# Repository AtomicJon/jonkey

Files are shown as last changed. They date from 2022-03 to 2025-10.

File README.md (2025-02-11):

# JONKEY

The JONKEY is a columnar split keyboard created using [ergogen](https://github.com/ergogen/ergogen).

## v2
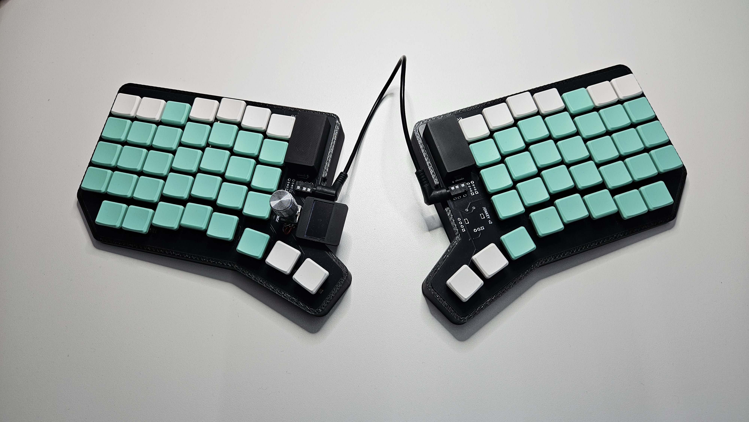
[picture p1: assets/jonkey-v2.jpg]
jonkey v2

#### What's New
- Swap thumb layout
- Added encoder mounts
- Added screen
- TODO: Touchpad mount

### Project Contents
- Ergogen Config: [jonkey-v2.yml](jonkey-v2.yml)
- PCB Design: [pcbs/](pcbs/)
- 3D Printable case: __TODO__
- QMK Config: [qmk_config/](qmk_config/)

## v1
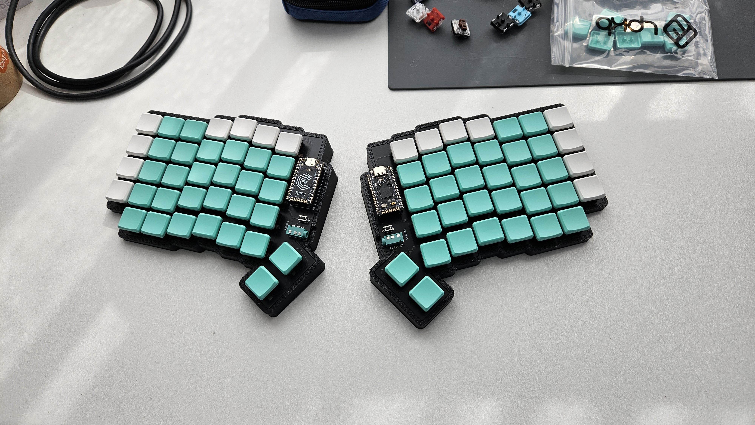
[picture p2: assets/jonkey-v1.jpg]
jonkey v1


### Project Contents
- Ergogen Config: [jonkey.yml](v1/jonkey.yml)
- PCB Design: [v1/pcbs/v1.1/](v1/pcbs/v1.1/)
- 3D Printable case: [case/](v1/case/)
  - The newest version has a 5 degree slope and tighter tolerances
    - [Left](v1/case/Case%20-%20Left%20-%205deg.stl)
    - [Right](v1/case/Case%20-%20Right%20-%205deg.stl)
- QMK Config: [qmk_config/](v1/qmk_config/)

## Notes
- The PCB is a single reversible board, flip it over for the right side
- The Pro Micros need to be attached upside down on the left and right side up on the right for the correct pin alignments
- Currently the QMK firmware has the side hardcoded and needs to be complied individually for each side. To switch between compiling the left/right side firmware, uncomment the appropriate line in the [config.h](v1/qmk_config/atomicjon/jonkey/config.h) (Lines 16/17)
  - There are free pins (D2, D3) that could be used for high/low indication of side

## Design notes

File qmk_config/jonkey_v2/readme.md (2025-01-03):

# atomicjon/jonkey_v2

atomicjon/jonkey_v2

*A short description of the keyboard/project*

* Keyboard Maintainer: [Jon](https://github.com/AtomicJon)
* Hardware Supported: Custom PCB - see the [jonkey](https://github.com/AtomicJon/jonkey) for PCB files
* Hardware Availability: DIY - see above

Before making, ensure the correct target board is configured in [`keyboard.json`](./keyboard.json)
E.g. For pro micro:
```json
"development_board": "promicro",
```

Make example for this keyboard (after setting up your build environment):

    make atomicjon/jonkey_v2:default

Flashing example for this keyboard:

    make atomicjon/jonkey_v2:default:flash

See the [build environment setup](https://docs.qmk.fm/#/getting_started_build_tools) and the [make instructions](https://docs.qmk.fm/#/getting_started_make_guide) for more information. Brand new to QMK? Start with our [Complete Newbs Guide](https://docs.qmk.fm/#/newbs).

## Bootloader

Enter the bootloader in 3 ways:

* **Bootmagic reset**: Hold down the key at (0,0) in the matrix (usually the top left key or Escape) and plug in the keyboard
* **Physical reset button**: Briefly press the button on the back of the PCB - some may have pads you must short instead
* **Keycode in layout**: Press the key mapped to `QK_BOOT` if it is available

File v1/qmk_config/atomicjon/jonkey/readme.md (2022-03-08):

# jonkey

jonkey

*A short description of the keyboard/project*

* Keyboard Maintainer: [Jon](https://github.com/AtomicJon)
* Hardware Supported: *The PCBs, controllers supported*
* Hardware Availability: *Links to where you can find this hardware*

Make example for this keyboard (after setting up your build environment):

    make jonkey:default

Flashing example for this keyboard:

    make jonkey:default:flash

See the [build environment setup](https://docs.qmk.fm/#/getting_started_build_tools) and the [make instructions](https://docs.qmk.fm/#/getting_started_make_guide) for more information. Brand new to QMK? Start with our [Complete Newbs Guide](https://docs.qmk.fm/#/newbs).

## Bootloader

Enter the bootloader in 3 ways:

* **Bootmagic reset**: Hold down the key at (0,0) in the matrix (usually the top left key or Escape) and plug in the keyboard
* **Physical reset button**: Briefly press the button on the back of the PCB - some may have pads you must short instead
* **Keycode in layout**: Press the key mapped to `RESET` if it is available

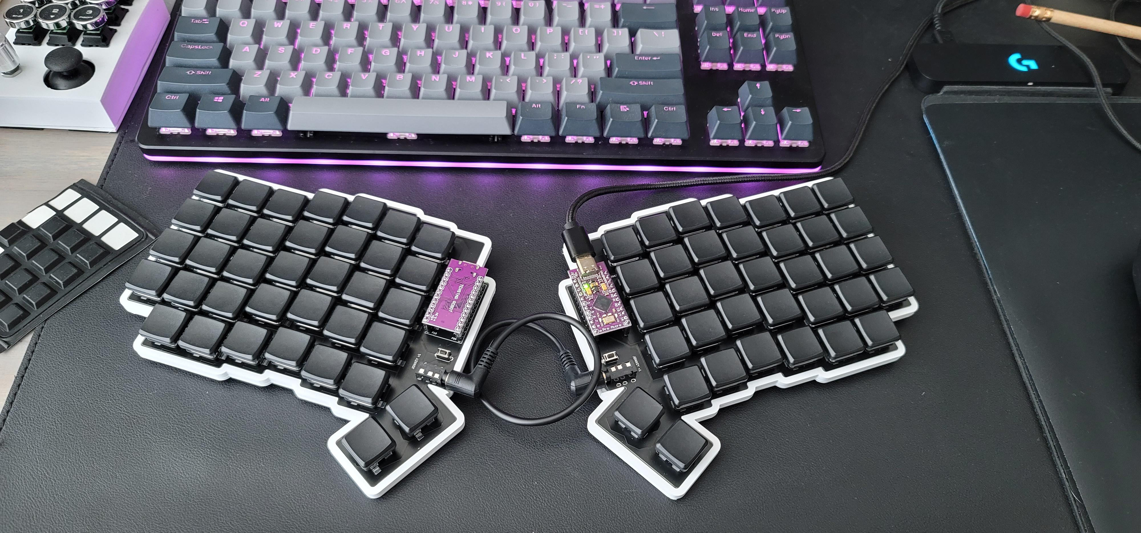
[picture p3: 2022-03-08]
assets/jonkey-v1.orig.jpg

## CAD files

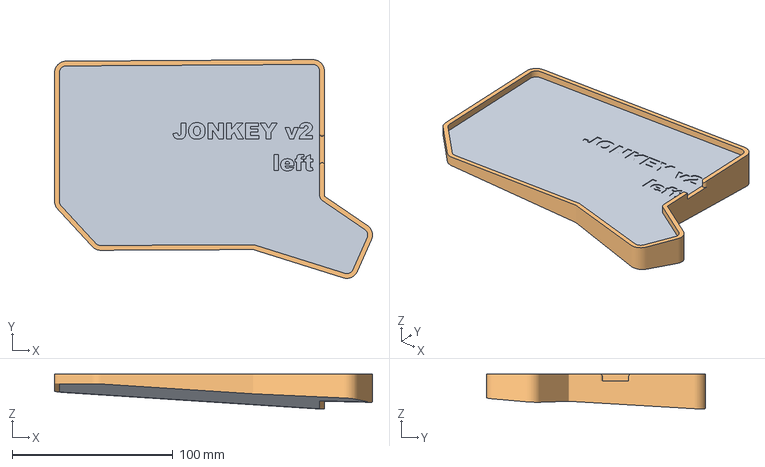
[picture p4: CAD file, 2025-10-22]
case/CaseLeft.3mf
197.9 x 136.1 x 21.7 mm

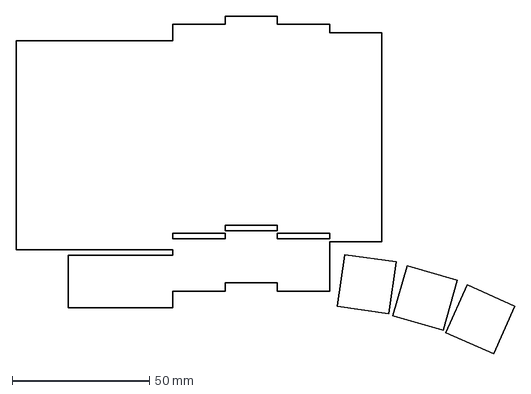
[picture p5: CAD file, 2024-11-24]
ergogen_output/keys.dxf
181.3 x 122.8 mm

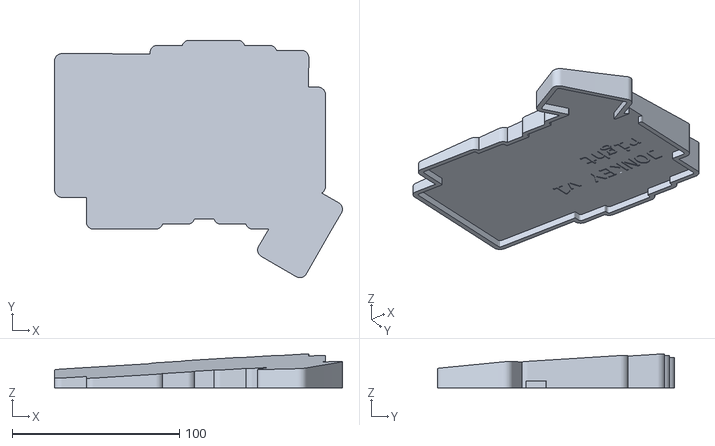
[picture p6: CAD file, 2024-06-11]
v1/case/Case - Right - 5deg.stl
172.1 x 141.8 x 20.3

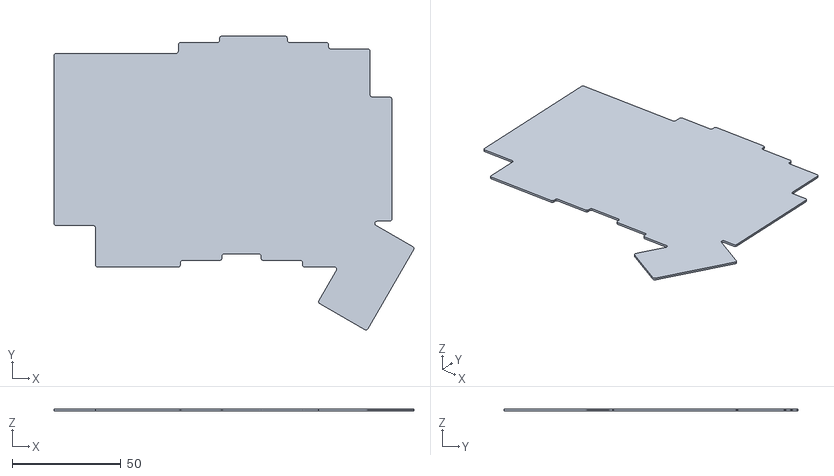
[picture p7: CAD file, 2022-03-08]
v1/ergogen_output/jonkey/cases/baseplate.stl
165.1 x 134.9 x 1.00

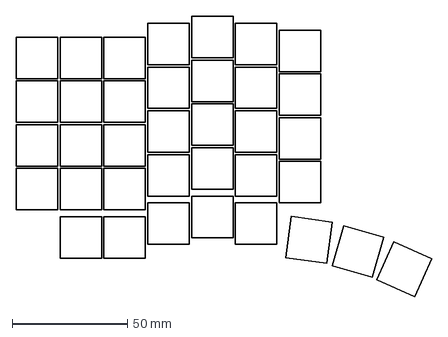
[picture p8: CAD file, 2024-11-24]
ergogen_output/demo.dxf
180.2 x 121.7 mm

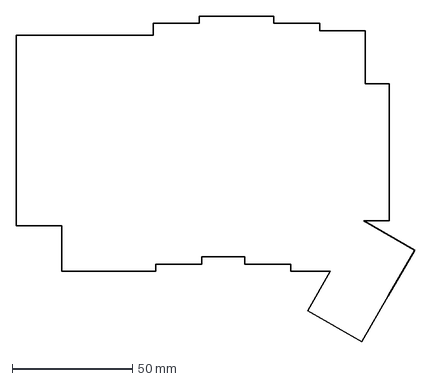
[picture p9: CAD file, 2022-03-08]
v1/ergogen_output/jonkey/outlines/raw.dxf
165.5 x 135.3 mm

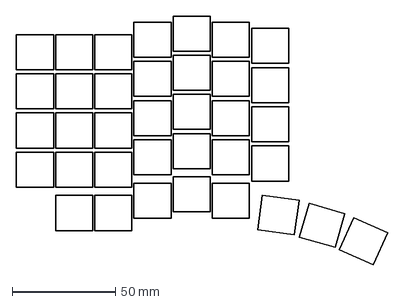
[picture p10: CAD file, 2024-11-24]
ergogen_output/keycap_outlines.dxf
180.0 x 120.7 mm

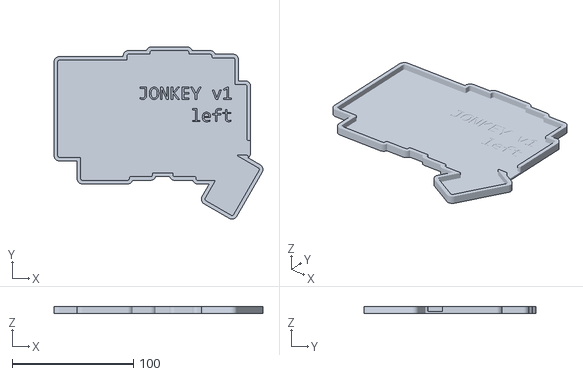
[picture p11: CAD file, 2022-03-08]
v1/case/Case - Left - v1.stl
172.2 x 141.9 x 5.80

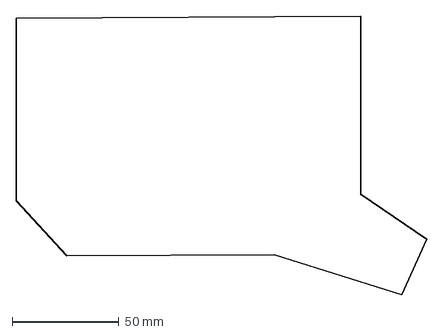
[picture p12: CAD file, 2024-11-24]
ergogen_output/board.dxf
192.4 x 130.6 mm

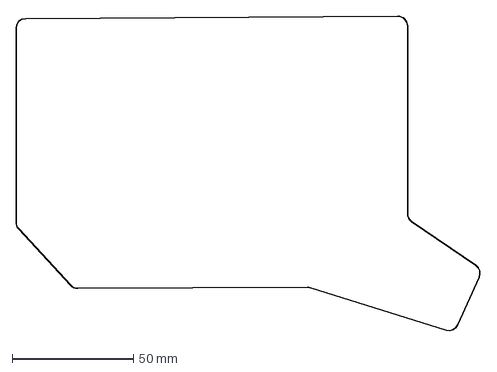
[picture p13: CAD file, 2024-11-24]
ergogen_output/cutout.dxf
191.8 x 130.1 mm

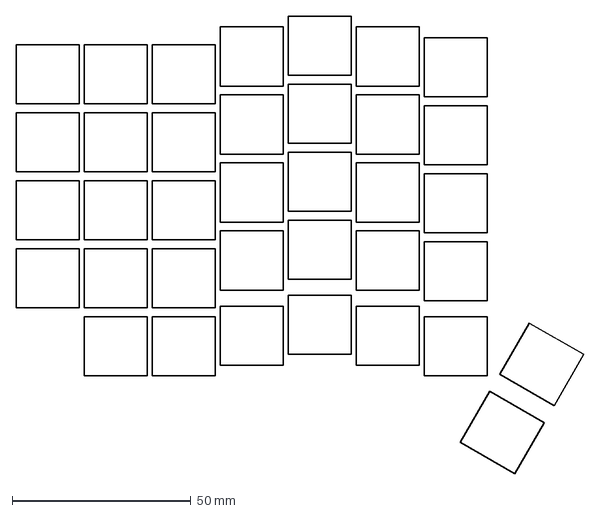
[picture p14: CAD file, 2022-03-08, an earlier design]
v1/ergogen_output/jonkey/outlines/keycap_outlines.dxf
158.5 x 127.8 mm

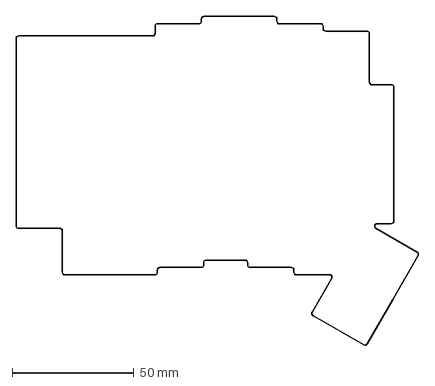
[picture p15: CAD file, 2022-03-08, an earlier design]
v1/ergogen_output/jonkey/outlines/cutout.dxf
165.3 x 135.1 mm

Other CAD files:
case/CaseRight.3mf
v1/case/Case - Left - 5deg.stl
v1/case/Case - Right - v1.stl
case/CaseLeft.stl
case/CaseRight.stl

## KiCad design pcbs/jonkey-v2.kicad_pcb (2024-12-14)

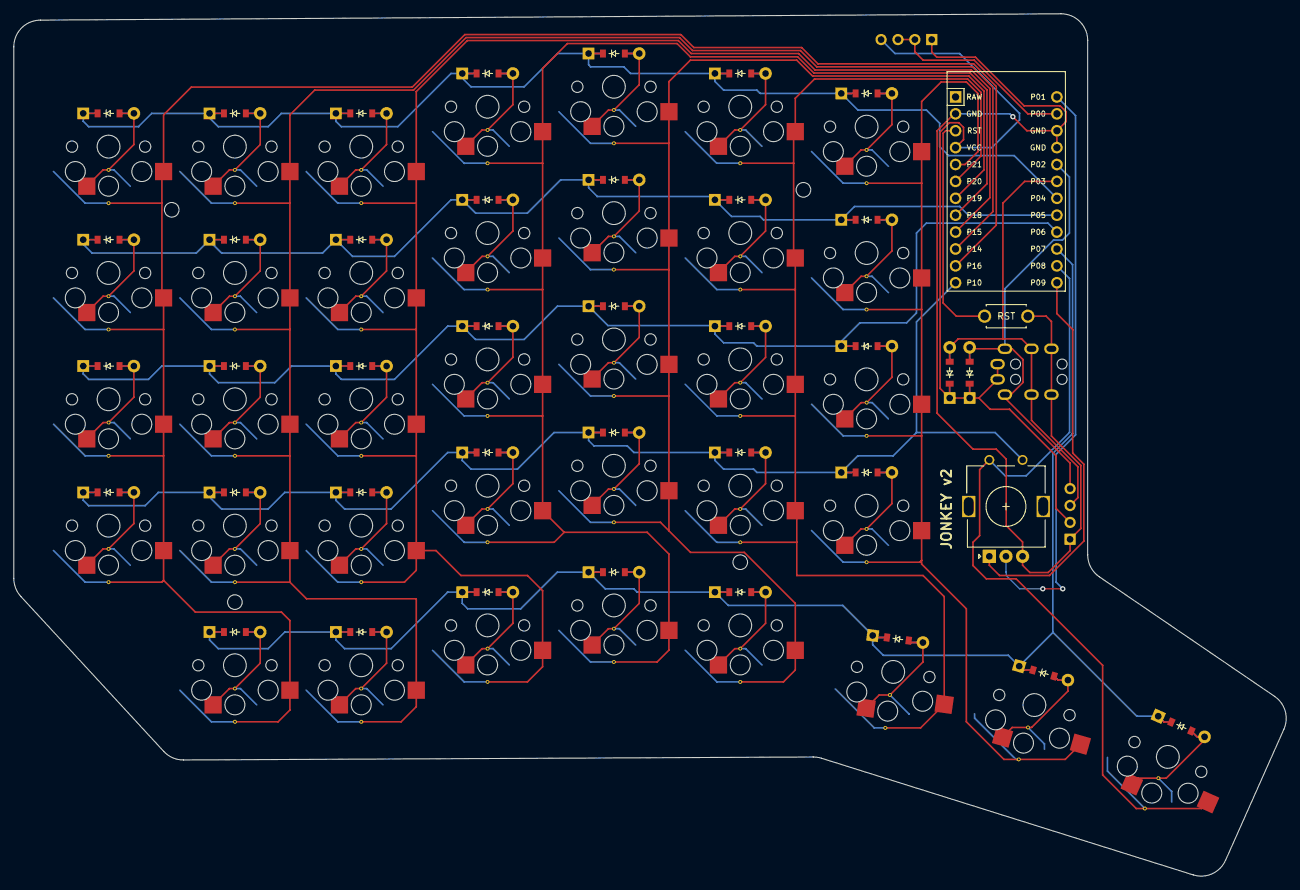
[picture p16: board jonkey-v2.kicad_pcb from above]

Board: 2 copper layers, 191.4 x 129.7 mm, 84 parts (0 on the bottom side), 57 nets.

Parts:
D1, D2, D3, D4, D5, D6, D7, D8, D9, D10, D11, D12, D13, D14, D15, D16, D17, D18, D19, D20, D21, D22, D23, D24, D25, D26, D27, D28, D29, D30, D31, D32, D33, D34, D35, D36: ComboDiode
MCU1: ProMicro
MH1, MH2, MH3, MH4: mounting_hole_npth
OLED1: OLED; OLED_headers
R11, R21: ComboDiode
ROT1: rotary_encoder
RST1: reset_switch_tht_top
S1, S2, S3, S4, S5, S6, S7, S8, S9, S10, S11, S12, S13, S14, S15, S16, S17, S18, S19, S20, S21, S22, S23, S24, S25, S26, S27, S28, S29, S30, S31, S32, S33, S34, S35, S36: PG1350
SERIAL1: SERIAL; OLED_headers
TRRS1: TRRS-PJ-320A-dual

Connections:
GND: MCU1.2, MCU1.15, MCU1.16, OLED1.1, ROT1.B, RST1.1, SERIAL1.1, TRRS1.4
P0: MCU1.14, SERIAL1.2, SERIAL1.3
P1: MCU1.13, ROT1.C
P2: MCU1.17, OLED1.4, R21.2, TRRS1.2
P3: MCU1.18, OLED1.3, R11.2, TRRS1.3
P4: D4.1, D9.1, D14.1, D19.1, D24.1, D29.1, D33.1, MCU1.19
P5: D3.1, D8.1, D13.1, D18.1, D23.1, D28.1, D32.1, MCU1.20
P6: D2.1, D7.1, D12.1, D17.1, D22.1, D27.1, D31.1, MCU1.21
P7: D5.1, D10.1, D15.1, D20.1, D25.1, D34.1, D35.1, D36.1, MCU1.22
P8: MCU1.23, ROT1.1, S36.2
P9: MCU1.24, ROT1.A
P10: D1.1, D6.1, D11.1, D16.1, D21.1, D26.1, D30.1, MCU1.12, ROT1.2
P14: MCU1.10, S6.2, S7.2, S8.2, S9.2, S10.2
P15: MCU1.9, S11.2, S12.2, S13.2, S14.2, S15.2
P16: MCU1.11, S1.2, S2.2, S3.2, S4.2, S5.2
P18: MCU1.8, S16.2, S17.2, S18.2, S19.2, S20.2
P19: MCU1.7, S21.2, S22.2, S23.2, S24.2, S25.2
P20: MCU1.6, S26.2, S27.2, S28.2, S29.2, S34.2
P21: MCU1.5, S30.2, S31.2, S32.2, S33.2, S35.2
RST: MCU1.3, RST1.2
VCC: MCU1.4, OLED1.2, R11.1, R21.1, SERIAL1.4, TRRS1.1
index_bottom: D26.2, S26.1
index_home: D27.2, S27.1
index_modifiers: D25.2, S25.1
index_numbers: D29.2, S29.1
index_top: D28.2, S28.1
inner1_bottom: D30.2, S30.1
inner1_home: D31.2, S31.1
inner1_numbers: D33.2, S33.1
inner1_thumbrow: D34.2, S34.1
inner1_top: D32.2, S32.1
middle_bottom: D21.2, S21.1
middle_home: D22.2, S22.1
middle_modifiers: D20.2, S20.1
middle_numbers: D24.2, S24.1
middle_top: D23.2, S23.1
outer1_bottom: D6.2, S6.1
outer1_home: D7.2, S7.1
outer1_modifiers: D5.2, S5.1
outer1_numbers: D9.2, S9.1
outer1_top: D8.2, S8.1
outer2_bottom: D1.2, S1.1
outer2_home: D2.2, S2.1
outer2_numbers: D4.2, S4.1
outer2_top: D3.2, S3.1
pinky_bottom: D11.2, S11.1
pinky_home: D12.2, S12.1
pinky_modifiers: D10.2, S10.1
pinky_numbers: D14.2, S14.1
pinky_top: D13.2, S13.1
ring_bottom: D16.2, S16.1
ring_home: D17.2, S17.1
ring_modifiers: D15.2, S15.1
ring_numbers: D19.2, S19.1
ring_top: D18.2, S18.1
thumb1_thumbrow: D35.2, S35.1
thumb2_thumbrow: D36.2, S36.1

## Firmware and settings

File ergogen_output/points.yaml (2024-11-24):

matrix_outer2_bottom:
  x: 0
  'y': 21
  r: 0
  meta:
    stagger: 0
    spread: 19
    splay: 0
    origin:
      - 0
      - 0
    orient: 0
    shift:
      - 0
      - 0
    rotate: 0
    adjust: {}
    width: 18
    height: 18
    padding: 19
    autobind: 10
    skip: false
    asym: both
    colrow: outer2_bottom
    name: matrix_outer2_bottom
    column_net: P16
    row_net: P10
    bind:
      - 1
      - 1
      - 1
      - 1
    zone: &ref_1
      columns:
        outer2: &ref_0
          key:
            column_net: P16
          rows:
            modifiers:
              skip: true
          name: outer2
        outer1: &ref_2
          key:
            stagger: 0
            column_net: P14
          rows:
            modifiers:
              column_net: P16
          name: outer1
        pinky: &ref_3
          key:
            stagger: 0
            column_net: P15
          rows:
            modifiers:
              column_net: P14
          name: pinky
        ring: &ref_4
          key:
            stagger: 6
            column_net: P18
          rows:
            modifiers:
              column_net: P15
          name: ring
        middle: &ref_5
          key:
            stagger: 3
            column_net: P19
          rows:
            modifiers:
              column_net: P18
          name: middle
        index: &ref_6
          key:
            stagger: -3
            column_net: P20
          rows:
            modifiers:
              column_net: P19
          name: index
        inner1: &ref_7
          key:
            stagger: -3
            column_net: P21
          rows:
            modifiers:
              skip: true
          name: inner1
      rows:
        modifiers:
          row_net: P7
          padding: u + 2
          bind:
            - 1
            - 1
            - 1
            - 1
        bottom:
          row_net: P10
          bind:
            - 1
            - 1
            - 1
            - 1
        home:
          row_net: P6
          bind:
            - 1
            - 1
            - 1
            - 1
        top:
          row_net: P5
          bind:
            - 1
            - 1
            - 1
            - 1
        numbers:
          row_net: P4
          bind:
            - 4
            - 1
            - 1
            - 1
      name: matrix
    col: *ref_0
    row: bottom
matrix_outer2_home:
  x: 0
  'y': 40
  r: 0
  meta:
    stagger: 0
    spread: 19
    splay: 0
    origin:
      - 0
      - 0
    orient: 0
    shift:
      - 0
      - 0
    rotate: 0
    adjust: {}
    width: 18
    height: 18
    padding: 19
    autobind: 10
    skip: false
    asym: both
    colrow: outer2_home
    name: matrix_outer2_home
    column_net: P16
    row_net: P6
    bind:
      - 1
      - 1
      - 1
      - 1
    zone: *ref_1
    col: *ref_0
    row: home
matrix_outer2_top:
  x: 0
  'y': 59
  r: 0
  meta:
    stagger: 0
    spread: 19
    splay: 0
    origin:
      - 0
      - 0
    orient: 0
    shift:
      - 0
      - 0
    rotate: 0
    adjust: {}
    width: 18
    height: 18
    padding: 19
    autobind: 10
    skip: false
    asym: both
    colrow: outer2_top
    name: matrix_outer2_top
    column_net: P16
    row_net: P5
    bind:
      - 1
      - 1
      - 1
      - 1
    zone: *ref_1
    col: *ref_0
    row: top
matrix_outer2_numbers:
  x: 0
  'y': 78
  r: 0
  meta:
    stagger: 0
    spread: 19
    splay: 0
    origin:
      - 0
      - 0
    orient: 0
    shift:
      - 0
      - 0
    rotate: 0
    adjust: {}
    width: 18
    height: 18
    padding: 19
    autobind: 10
    skip: false
    asym: both
    colrow: outer2_numbers
    name: matrix_outer2_numbers
    column_net: P16
    row_net: P4
    bind:
      - 4
      - 1
      - 1
      - 1
    zone: *ref_1
    col: *ref_0
    row: numbers
matrix_outer1_modifiers:
  x: 19
  'y': 0
  r: 0
  meta:
    stagger: 0
    spread: 19
    splay: 0
    origin:
      - 0
      - 0
    orient: 0
    shift:
      - 0
      - 0
    rotate: 0
    adjust: {}
    width: 18
    height: 18
    padding: 21
    autobind: 10
    skip: false
    asym: both
    colrow: outer1_modifiers
    name: matrix_outer1_modifiers
    column_net: P16
    row_net: P7
    bind:
      - 1
      - 1
      - 1
      - 1
    zone: *ref_1
    col: *ref_2
    row: modifiers
matrix_outer1_bottom:
  x: 19
  'y': 21
  r: 0
  meta:
    stagger: 0
    spread: 19
    splay: 0
    origin:
      - 0
      - 0
    orient: 0
    shift:
      - 0
      - 0
    rotate: 0
    adjust: {}
    width: 18
    height: 18
    padding: 19
    autobind: 10
    skip: false
    asym: both
    colrow: outer1_bottom
    name: matrix_outer1_bottom
    column_net: P14
    row_net: P10
    bind:
      - 1
      - 1
      - 1
      - 1
    zone: *ref_1
    col: *ref_2
    row: bottom
matrix_outer1_home:
  x: 19
  'y': 40
  r: 0
  meta:
    stagger: 0
    spread: 19
    splay: 0
    origin:
      - 0
      - 0
    orient: 0
    shift:
      - 0
      - 0
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

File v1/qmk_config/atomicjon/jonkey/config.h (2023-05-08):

// Copyright 2022 Jon (@AtomicJon)
// SPDX-License-Identifier: GPL-2.0-or-later

#pragma once

// Should no longer be included
// #include "config_common.h"

/* USB Device descriptor parameter */
/*
⚠ atomicjon/jonkey: PRODUCT_ID in config.h is deprecated in favor of `usb.pid` in info.json and will be removed at a later date
⚠ atomicjon/jonkey: VENDOR_ID in config.h is deprecated in favor of `usb.vid` in info.json and will be removed at a later date
⚠ atomicjon/jonkey: PRODUCT in config.h is deprecated in favor of `keyboard_name` in info.json and will be removed at a later date
⚠ atomicjon/jonkey: MANUFACTURER in config.h is deprecated in favor of `manufacturer` in info.json and will be removed at a later date
⚠ atomicjon/jonkey: DEVICE_VER in config.h is deprecated in favor of `usb.device_version` in info.json and will be removed at a later date
*/
// #define VENDOR_ID    0xFEED
// #define PRODUCT_ID   0x0000
// #define DEVICE_VER   0x0001
// #define MANUFACTURER AtomicJon
// #define PRODUCT      jonkey

// Hardcoding handedness for now
#define MASTER_RIGHT
// #define MASTER_LEFT


/* key matrix size */
// Rows * 2 for left and right
#define MATRIX_ROWS 12
#define MATRIX_COLS 8

/*
 * Keyboard Matrix Assignments
 *
 * Change this to how you wired your keyboard
 * COLS: AVR pins used for columns, left to right
 * ROWS: AVR pins used for rows, top to bottom
 * DIODE_DIRECTION: COL2ROW = COL = Anode (+), ROW = Cathode (-, marked on diode)
 *                  ROW2COL = ROW = Anode (+), COL = Cathode (-, marked on diode)
 *
 */
// By Pin:              {  4,  5,  6, 10,  7,  8 }
#define MATRIX_ROW_PINS { D4, C6, D7, B6, E6, B4 }
// By Pin:              { 16, 14, 15, 18, 19, 20, 21,  9 }
#define MATRIX_COL_PINS { B2, B3, B1, F7, F6, F5, F4, B5 }
// By Pin:              { 0,   1 }
#define UNUSED_PINS     { D2, D3 }

/* COL2ROW, ROW2COL */
#define DIODE_DIRECTION COL2ROW

/*
 * Split Keyboard specific options, make sure you have 'SPLIT_KEYBOARD = yes' in your rules.mk, and define SOFT_SERIAL_PIN.
 */
// Pin 2 and 3 are cross connected via TRS, using 2 (3 is D0)
#define SOFT_SERIAL_PIN D1  // or D1, D2, D3, E6
// To use I2C, comment out the above line and uncomment the line below - requires adding pullup resistors on D0 and D1
// #define USE_I2C

// #define MOUSE_EXTENDED_REPORT

//#define LED_NUM_LOCK_PIN B0
//#define LED_CAPS_LOCK_PIN B1
//#define LED_SCROLL_LOCK_PIN B2
//#define LED_COMPOSE_PIN B3
//#define LED_KANA_PIN B4

//#define BACKLIGHT_PIN B7
//#define BACKLIGHT_LEVELS 3
//#define BACKLIGHT_BREATHING

//#define RGB_DI_PIN E2
//#ifdef RGB_DI_PIN
//#    define RGBLED_NUM 16
//#    define RGBLIGHT_HUE_STEP 8
//#    define RGBLIGHT_SAT_STEP 8
//#    define RGBLIGHT_VAL_STEP 8
//#    define RGBLIGHT_LIMIT_VAL 255 /* The maximum brightness level */
//#    define RGBLIGHT_SLEEP  /* If defined, the RGB lighting will be switched off when the host goes to sleep */
/*== all animations enable ==*/
//#    define RGBLIGHT_ANIMATIONS
/*== or choose animations ==*/
//#    define RGBLIGHT_EFFECT_BREATHING
//#    define RGBLIGHT_EFFECT_RAINBOW_MOOD
//#    define RGBLIGHT_EFFECT_RAINBOW_SWIRL
//#    define RGBLIGHT_EFFECT_SNAKE
//#    define RGBLIGHT_EFFECT_KNIGHT
//#    define RGBLIGHT_EFFECT_CHRISTMAS
//#    define RGBLIGHT_EFFECT_STATIC_GRADIENT
//#    define RGBLIGHT_EFFECT_RGB_TEST
//#    define RGBLIGHT_EFFECT_ALTERNATING
/*== customize breathing effect ==*/
/*==== (DEFAULT) use fixed table instead of exp() and sin() ====*/
//#    define RGBLIGHT_BREATHE_TABLE_SIZE 256      // 256(default) or 128 or 64
/*==== use exp() and sin() ====*/
//#    define RGBLIGHT_EFFECT_BREATHE_CENTER 1.85  // 1 to 2.7
//#    define RGBLIGHT_EFFECT_BREATHE_MAX    255   // 0 to 255
//#endif

/* Debounce reduces chatter (unintended double-presses) - set 0 if debouncing is not needed */
#define DEBOUNCE 5

/* define if matrix has ghost (lacks anti-ghosting diodes) */
//#define MATRIX_HAS_GHOST

/* Mechanical locking support. Use KC_LCAP, KC_LNUM or KC_LSCR instead in keymap */
#define LOCKING_SUPPORT_ENABLE
/* Locking resynchronize hack */
#define LOCKING_RESYNC_ENABLE

/* If defined, GRAVE_ESC will always act as ESC when CTRL is held.
 * This is useful for the Windows task manager shortcut (ctrl+shift+esc).
 */
//#define GRAVE_ESC_CTRL_OVERRIDE
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

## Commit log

2022-03-08 Check in v1 files
    [Case - Left - v1.stl, Case - Right - v1.stl, baseplate.stl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]
2023-01-28 Add comment regarding switching to I2C
    The board is wired for either serial or I2C for communication between sides. Currently serial is used, but I2C can be used by adding a pullup resistor between pins D0 and D1, commenting out `SOFT_SER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
2024-06-11 Add new cases with slope and tighter tolerances
    [Case - Left - 5deg.stl, Case - Right - 5deg.stl]
2024-11-17 feat(pcb): check in v1.1
    [jonkey-v1-B_Cu.gbr, jonkey-v1-B_Mask.gbr, jonkey-v1-B_Paste.gbr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]
2024-11-18 feat(v2): move v1 and add initial config for v2
    [Case - Left - 5deg.stl, Case - Left - v1.stl, Case - Right - 5deg.stl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]
2024-11-21 feat: add a few mounting holds, increase thumb distance, increase stagger beyound pinky
    [jonkey-v2.kicad_pcb]
2024-11-21 feat: add place for pull up resistors for i2c
    [jonkey-v2.kicad_pcb]
2024-11-24 feat: shift thumb column pins to free up 1 pin
    [board.dxf, cutout.dxf, demo.dxf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]
2024-11-24 feat: free up pin 0 incase its needed for serial coms and add access via 4 pins
    [jonkey-v2.kicad_pcb, main.kicad_pcb]
2024-11-25 feat: routing done + switch P2 and P3 resistor placement for easier routing
    [jonkey-v2.kicad_pcb, main.kicad_pcb]
2024-12-14 feat: check in latest PCBs (wrong pins for encoder)
    [jonkey-v2-B_Cu.gbr, jonkey-v2-B_Mask.gbr, jonkey-v2-B_Paste.gbr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]
2025-10-22 feat: check in v2 case files
    [CaseLeft.3mf, CaseLeft.stl, CaseRight.3mf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]
